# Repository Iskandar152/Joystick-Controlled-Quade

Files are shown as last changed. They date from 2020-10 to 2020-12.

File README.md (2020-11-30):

# Joystick-Controlled-Quade

## Project Goal

Creating a quadraped robot that uses an ultra sonic sensor and joystick to allow wireless control. The information from the ultra sonic sensor will allow the controller to guide the robot even if the controller cannot see where it is.

## MSP432 UART Connection

Based off [TI UART example code](http://dev.ti.com/tirex/explore/node?node=AHgBmlbzFK.HTw3HuKF7Cw__z-lQYNj__LATEST)
This example was chosen as the base because the baud rate was already set at 9600 which is necessary for communication with the Arduino Uno.

Altered to allow communication over the 3.2 and 3.3 pins on the MSP432 so that it can be connected to and Arduino Uno. It works with a receive interrupt that will then transmit the information from the ultra sonic sensor. 

## Arduino Blynk Code

Based off examples from the Blynk library, [Joystick Example](https://examples.blynk.cc/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) and [Virtual Display](https://examples.blynk.cc/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).
Our code combines these examples and alters the display so that it is comstantly updating whenever new data is available.

This was an easy way to have a wireless connection with the MSP432 that just needed the addition of the UART communication to work with the TX and RX pins. The code creates an array for the joystick inputs and writes the sensor values to a digital display.

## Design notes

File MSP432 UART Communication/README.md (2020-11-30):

# MSP432 UART Communication

## Preface
This code is based off the [TI UART example code](http://dev.ti.com/tirex/explore/node?node=AHgBmlbzFK.HTw3HuKF7Cw__z-lQYNj__LATEST)

## Information
This code is the base for the UART communication through the 3.2 and 3.3 pins that works with a reciving interrupt.
This is used so that we can transmit the ultra sonic sensor values through the UART to the Arduino.

This allows us to utialize that Blynk libraries that work with Arduinos to transmit the information wirelessly using the ESP8266 esp-01 module.

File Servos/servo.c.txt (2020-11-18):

//SMCLK = 48MHZ/4 = 12 MHZ, 83.33 ns
//Counter counts up to TA0CCR0 and backs down
//Let Timerclock period T = 8/12MHZ = 666.7ns
//Period of P2.4 is period * 1.333 us, duty cycle is duty / period
//Period of P2.5 is period * 1.333 us, duty cycle is duty2/period
Referenced from the Texas Instruments training videos, will be changing it up a little to be more specific to our project 
//https://training.ti.com/ti-rslk-module-13-lab-video-13-2-interrupt-latency?context=1135347-1139304-1134881
#include<msp.h> //Include the library files for the board. This includes the msp432p401r

void PWM_Init12(uint16_t period, uint16_t duty1, uint16_t duty2){
    P2 -> DIR |= 0x30;     //P2.4, P2.5 output
    P2 -> SEL0 |= 0x30;    //P2.4, P2.5 Timer 0A functions
    P2 -> SEL1 &= -0x30;   //P2.4, P2.5 Timer0A functions
    TIMER_A0 -> CCTL[0] = 0x0080;    //CCIO toggle
    TIMER_A0 -> CCR[0] = period;     //Period is 2*period*8*83.33ns is 1.333*period
    TIMER_A0 -> EX0 = 0x0000;        //divide by 1
    TIMER_A0 -> CCTL[1] = 0x0040;    //CCR1 toggle/reset
    TIMER_A0 -> CCR[1] = duty1;      //CCR1 duty cycle is duty1/period
    TIMER_A0 -> CTL = 0x02F0;         //SMCLK = 12MHZ, divide by 8, up-down mode

}

//change duty cycle of PWM output on P2.4
//Inputs: duty1
//Outputs: None
//Period of P2.4 is 2*period*666.7ns, duty cycle is duty1/period
void PWM_Duty1(uint16_t duty1){
    TIMER_A0 -> CCR[1] = duty1;
}

void PWM_Duty2(uint16_t duty2){
    TIMER_A0 -> CCR[2] = duty2;
}

int main(void){
    WDT_A->CTL= WDT_A_CTL_PW | WDT_A_CTL_HOLD; //Stop watchdog timer
    PWM_Init12(1.5,1,1);
    PWM_Duty1(2);
    /*
    while(1){
        PWM_Init12(1.5,1,1);
        //P2 -> OUT |= 0x01;
        //for(int i = 0; i < 50000; i++);
        //P2 -> OUT ^= 0x01;
    }
    */
}

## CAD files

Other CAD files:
MSP432 UART Communication/Debug/ccs/startup_msp432p401r_ccs.obj

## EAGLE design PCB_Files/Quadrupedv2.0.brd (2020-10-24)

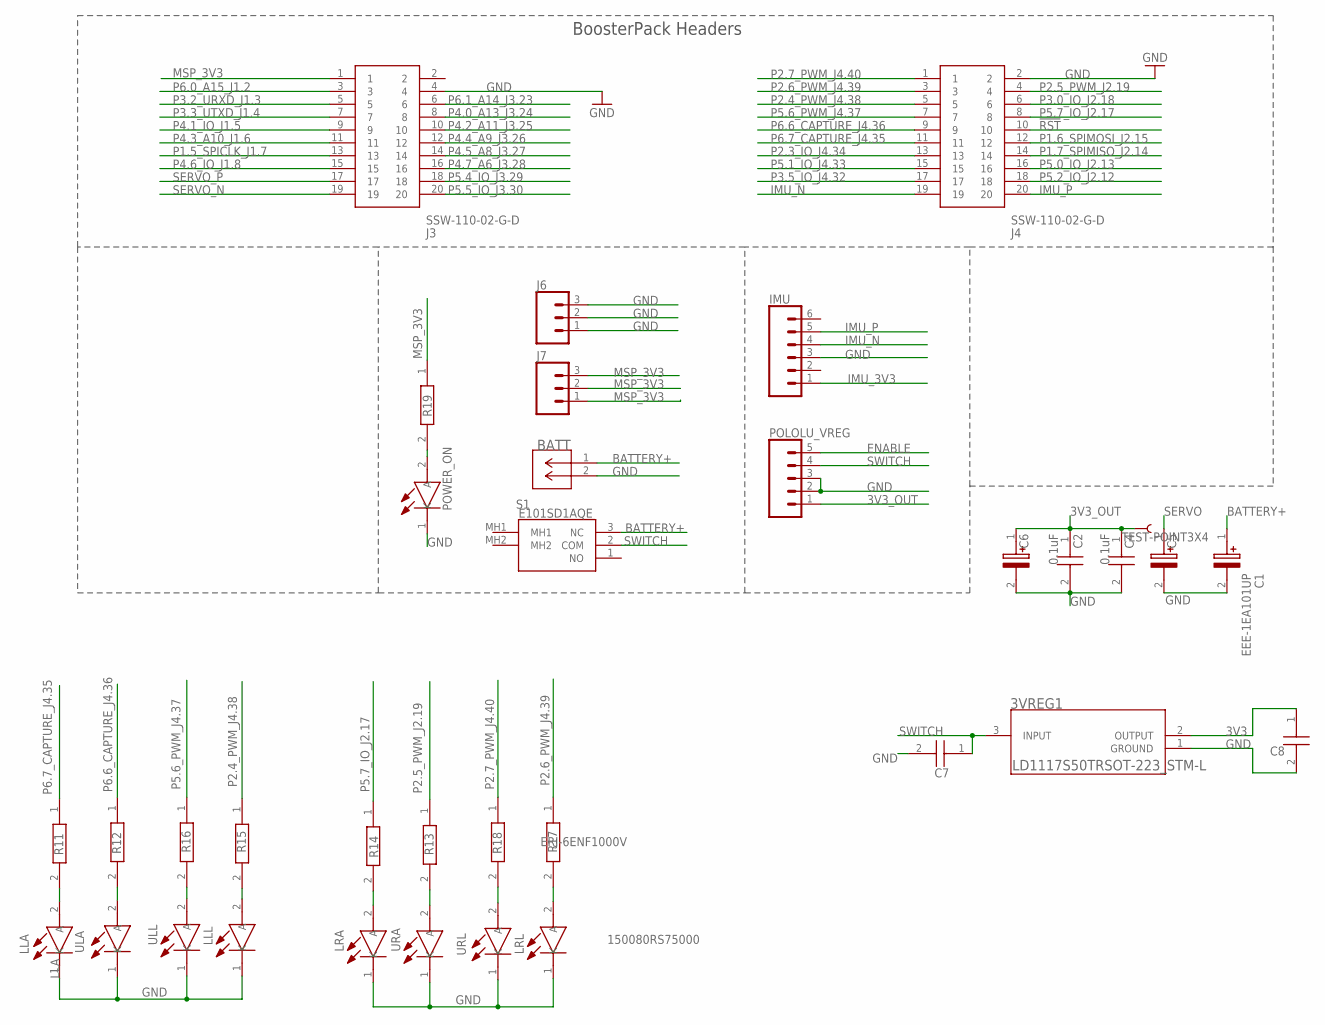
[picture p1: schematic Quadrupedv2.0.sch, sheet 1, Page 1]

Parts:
3VREG1: LD1117S50TRSOT-223_STM-L; SOT-223_STM-L
BATT: 640456-2; CONN2_640456-2_TEC
C1, C5, C6: EEE-1EA101UP; CAPAE830X650N
C2, C4: 0.1uF; CAPC2012X88N
C7, C8: C0805C104K5RAC7411; CAPC2012X88N
IMU: CONN_06SILK_FEMALE_PTH; 1X06
J3, J4: SSW-110-02-G-D; SAMTEC_SSW-110-02-G
J6, J7: CONN_03CONN_3F; 1X03_FEMALE
LLA: 150080RS75000; LEDC2012X80N
LLL: 150080RS75000; LEDC2012X80N
LRA: 150080RS75000; LEDC2012X80N
LRL: 150080RS75000; LEDC2012X80N
POLOLU_VREG: CONN_05; 1X05
POWER_ON: 150080RS75000; LEDC2012X80N
R11, R12, R13, R14, R15, R16, R17, R18, R19: ERJ-6ENF1000V; RESC2012X70N
S1: E101SD1AQE
TP22: TEST-POINT3X4; PAD.03X.04
ULA: 150080RS75000; LEDC2012X80N
ULL: 150080RS75000; LEDC2012X80N
URA: 150080RS75000; LEDC2012X80N
URL: 150080RS75000; LEDC2012X80N

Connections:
3V3: 3VREG1.2 (OUTPUT), C8.1; also elsewhere on the board
3V3_OUT: C2.1, C4.1, C6.1 (+), POLOLU_VREG.1, TP22.P$1; also elsewhere on the board
!RST: J4.10
BATTERY+: BATT.1, C1.1 (+), S1.3 (NC)
ENABLE: POLOLU_VREG.5
GND: 3VREG1.1 (GROUND), BATT.2, C1.2 (-), C2.2, C4.2, C5.2 (-), C6.2 (-), C7.2, C8.2, IMU.3, J3.4, J4.2, J6.1, J6.2, J6.3, LLA.1 (K), LLL.1 (K), LRA.1 (K), LRL.1 (K), POLOLU_VREG.2, POLOLU_VREG.3, POWER_ON.1 (K), ULA.1 (K), ULL.1 (K), URA.1 (K), URL.1 (K); also elsewhere on the board
IMU_3V3: IMU.1; also elsewhere on the board
IMU_N: IMU.4, J4.19
IMU_P: IMU.5, J4.20
MSP_3V3: J3.1, J7.1, J7.2, J7.3, R19.1; also elsewhere on the board
unnamed: R12.2, ULA.2 (A)
unnamed: LLA.2 (A), R11.2
unnamed: R16.2, ULL.2 (A)
unnamed: LLL.2 (A), R15.2
unnamed: R13.2, URA.2 (A)
unnamed: LRA.2 (A), R14.2
unnamed: R18.2, URL.2 (A)
unnamed: LRL.2 (A), R17.2
unnamed: POWER_ON.2 (A), R19.2
P1.5_SPICLK_J1.7: J3.13
P1.6_SPIMOSI_J2.15: J4.12
P1.7_SPIMISO_J2.14: J4.14
P2.3_IO_J4.34: J4.13
P2.4_PWM_J4.38: J4.5, R15.1
P2.5_PWM_J2.19: J4.4, R13.1
P2.6_PWM_J4.39: J4.3, R17.1
P2.7_PWM_J4.40: J4.1, R18.1
P3.0_IO_J2.18: J4.6
P3.2_URXD_J1.3: J3.5
P3.3_UTXD_J1.4: J3.7
P3.5_IO_J4.32: J4.17
P4.0_A13_J3.24: J3.8
P4.1_IO_J1.5: J3.9
P4.2_A11_J3.25: J3.10
P4.3_A10_J1.6: J3.11
P4.4_A9_J3.26: J3.12
P4.5_A8_J3.27: J3.14
P4.6_IO_J1.8: J3.15
P4.7_A6_J3.28: J3.16
P5.0_IO_J2.13: J4.16
P5.1_IO_J4.33: J4.15
P5.2_IO_J2.12: J4.18
P5.4_IO_J3.29: J3.18
P5.5_IO_J3.30: J3.20
P5.6_PWM_J4.37: J4.7, R16.1
P5.7_IO_J2.17: J4.8, R14.1
P6.0_A15_J1.2: J3.3
P6.1_A14_J3.23: J3.6
P6.6_CAPTURE_J4.36: J4.9, R12.1
P6.7_CAPTURE_J4.35: J4.11, R11.1
SERVO: C5.1 (+); also elsewhere on the board
SERVO_N: J3.19; also elsewhere on the board
SERVO_P: J3.17; also elsewhere on the board
SWITCH: 3VREG1.3 (INPUT), C7.1, POLOLU_VREG.4, S1.2 (COM)

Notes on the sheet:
BoosterPack Headers

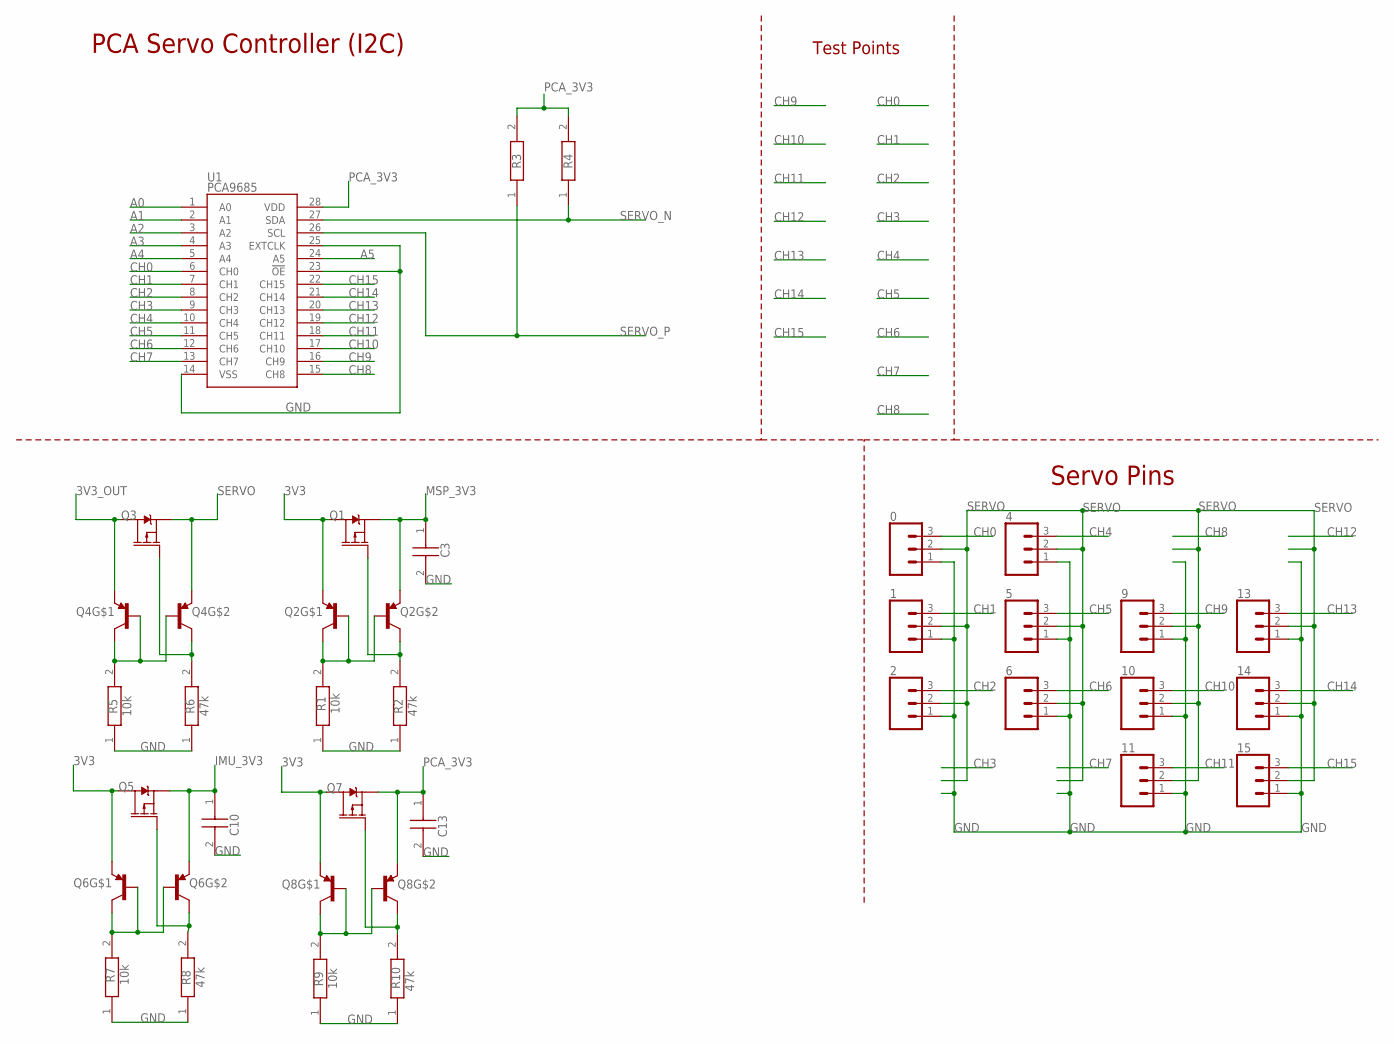
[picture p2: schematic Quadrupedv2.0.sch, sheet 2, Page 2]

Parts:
0, 1, 2, 4, 5, 6, 9, 10, 11, 13, 14, 15: CONN_03; 1X03MALE
C3, C10, C13: C0805C104K5RAC7411; CAPC2012X88N
Q1, Q3, Q5, Q7: 2.5A/30V/105mΩ; SOT23-3
Q2, Q4, Q6, Q8: TRANS_PNP_DUALSOT-363; SOT363_PHILIPS
R1, R5, R7, R9: 10k; RESC2012X70N
R2, R6, R8, R10: 47k; RESC2012X70N
R3, R4: ERJ-6ENF1000V; RESC2012X70N
U1: PCA9685; TSSOP-28_4MM

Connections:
3V3: Q1.3 (D), Q2.1 (E), Q5.3 (D), Q6.1 (E), Q7.3 (D), Q8.1 (E); also elsewhere on the board
3V3_OUT: Q3.3 (D), Q4.1 (E); also elsewhere on the board
A0: U1.1 (A0)
A1: U1.2 (A1)
A2: U1.3 (A2)
A3: U1.4 (A3)
A4: U1.5 (A4)
A5: U1.24 (A5)
CH0: 0.3, U1.6 (CH0)
CH1: 1.3, U1.7 (CH1)
CH2: 2.3, U1.8 (CH2)
CH3: U1.9 (CH3)
CH4: 4.3, U1.10 (CH4)
CH5: 5.3, U1.11 (CH5)
CH6: 6.3, U1.12 (CH6)
CH7: U1.13 (CH7)
CH8: U1.15 (CH8)
CH9: 9.3, U1.16 (CH9)
CH10: 10.3, U1.17 (CH10)
CH11: 11.3, U1.18 (CH11)
CH12: U1.19 (CH12)
CH13: 13.3, U1.20 (CH13)
CH14: 14.3, U1.21 (CH14)
CH15: 15.3, U1.22 (CH15)
GND: 0.1, 1.1, 2.1, 4.1, 5.1, 6.1, 9.1, 10.1, 11.1, 13.1, 14.1, 15.1, C3.2, C10.2, C13.2, R1.1, R2.1, R5.1, R6.1, R7.1, R8.1, R9.1, R10.1, U1.14 (VSS), U1.23 (!OE), U1.25 (EXTCLK); also elsewhere on the board
IMU_3V3: C10.1, Q5.2 (S), Q6.4 (E); also elsewhere on the board
MSP_3V3: C3.1, Q1.2 (S), Q2.4 (E); also elsewhere on the board
unnamed: Q7.1 (G), Q8.3 (C), R10.2
unnamed: Q8.2 (B), Q8.5 (B), Q8.6 (C), R9.2
unnamed: Q1.1 (G), Q2.3 (C), R2.2
unnamed: Q2.2 (B), Q2.5 (B), Q2.6 (C), R1.2
unnamed: Q5.1 (G), Q6.3 (C), R8.2
unnamed: Q6.2 (B), Q6.5 (B), Q6.6 (C), R7.2
unnamed: Q4.2 (B), Q4.5 (B), Q4.6 (C), R5.2
unnamed: Q3.1 (G), Q4.3 (C), R6.2
PCA_3V3: C13.1, Q7.2 (S), Q8.4 (E), R3.2, R4.2, U1.28 (VDD)
SERVO: 0.2, 1.2, 2.2, 4.2, 5.2, 6.2, 9.2, 10.2, 11.2, 13.2, 14.2, 15.2, Q3.2 (S), Q4.4 (E); also elsewhere on the board
SERVO_N: R4.1, U1.27 (SDA); also elsewhere on the board
SERVO_P: R3.1, U1.26 (SCL); also elsewhere on the board

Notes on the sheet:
PCA Servo Controller (I2C)
Test Points
Servo Pins

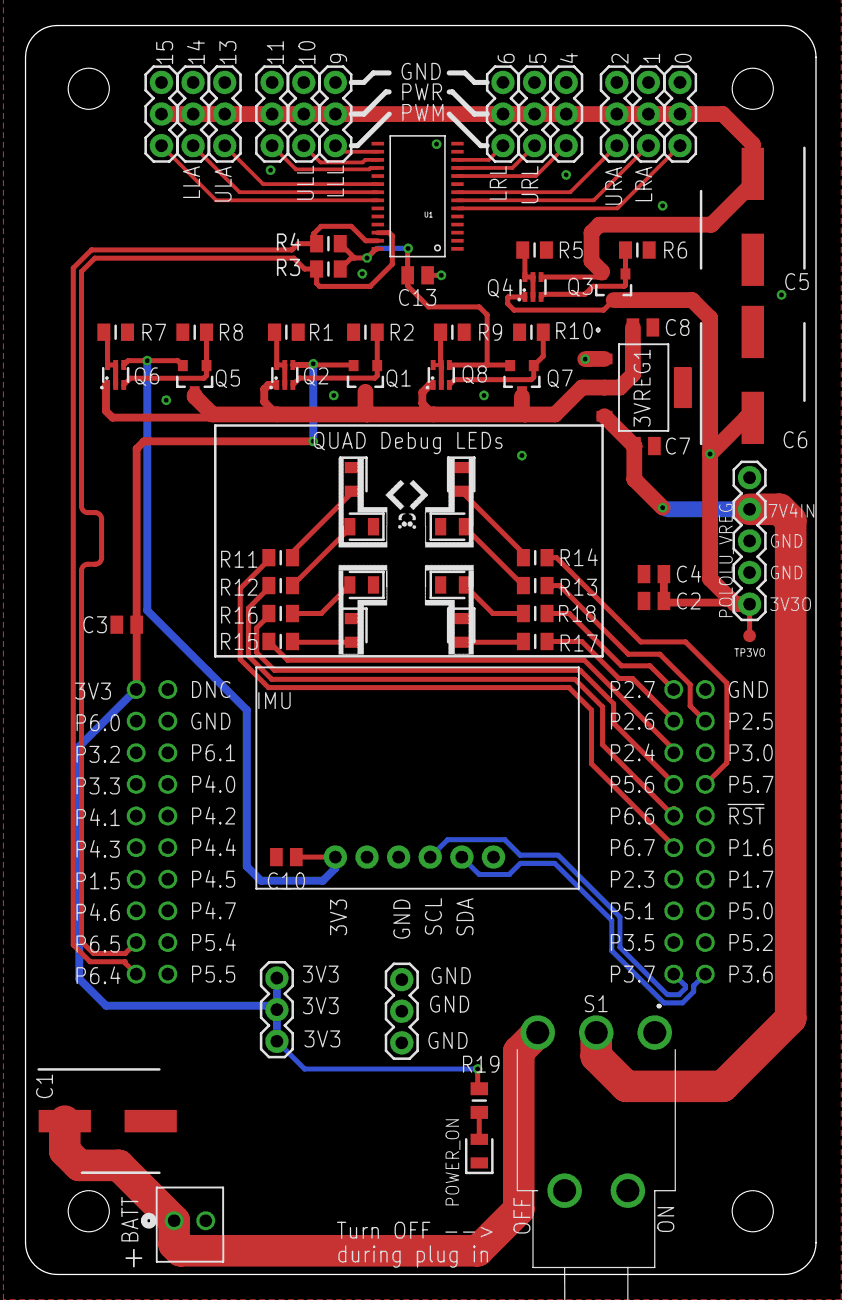
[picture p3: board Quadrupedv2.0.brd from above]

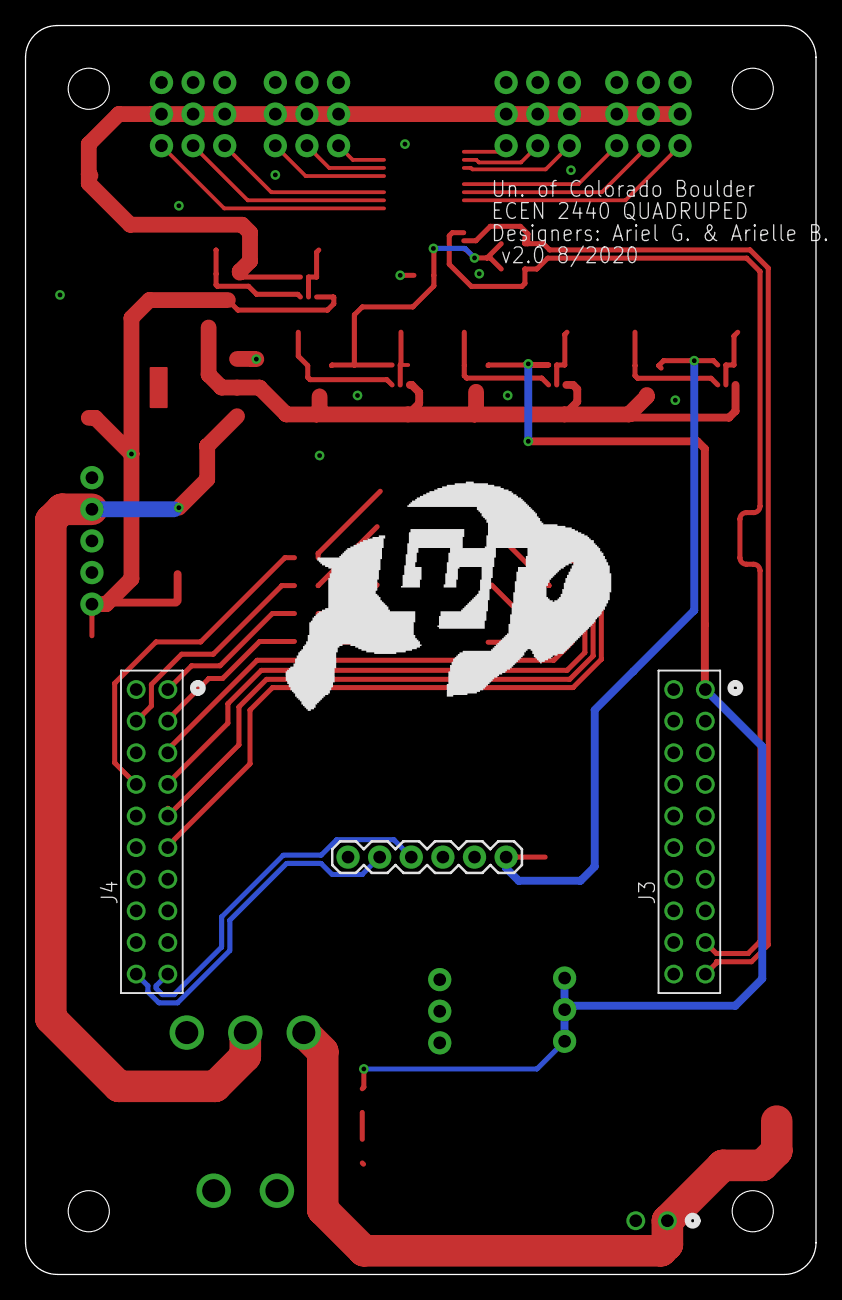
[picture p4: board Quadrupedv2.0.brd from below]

Board: 2 copper layers, 63.5 x 100.3 mm, 71 parts (4 on the bottom side), 50 nets.

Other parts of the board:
U$1: DEBUGLEDS
U$2: SKUBUFFS

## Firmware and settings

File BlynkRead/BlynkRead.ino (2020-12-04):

/*************************************************************
  Download latest Blynk library here:
    https://github.com/blynkkk/blynk-library/releases/latest

  Blynk is a platform with iOS and Android apps to control
  Arduino, Raspberry Pi and the likes over the Internet.
  You can easily build graphic interfaces for all your
  projects by simply dragging and dropping widgets.

    Downloads, docs, tutorials: http://www.blynk.cc
    Sketch generator:           http://examples.blynk.cc
    Blynk community:            http://community.blynk.cc
    Follow us:                  http://www.fb.com/blynkapp
                                http://twitter.com/blynk_app

  Blynk library is licensed under MIT license
  This example code is in public domain.

 *************************************************************
  WARNING!
    It's very tricky to get it working. Please read this article:
    http://help.blynk.cc/hardware-and-libraries/arduino/esp8266-with-at-firmware

  This example shows how to send values to the Blynk App,
  when there is a widget, attached to the Virtual Pin and it
  is set to some frequency

  Project setup in the app:
    Value Display widget attached to V5. Set any reading
    frequency (i.e. 1 second)
 *************************************************************/

/* Comment this out to disable prints and save space */
#define BLYNK_PRINT Serial


#include <ESP8266_Lib.h>
#include <BlynkSimpleShieldEsp8266.h>

int datain;

// You should get Auth Token in the Blynk App.
// Go to the Project Settings (nut icon).
char auth[] = "YourAuthToken";

// Your WiFi credentials.
// Set password to "" for open networks.
char ssid[] = "YourNetworkName";
char pass[] = "YourPassword";

// or Software Serial on Uno, Nano...
#include <SoftwareSerial.h>
SoftwareSerial EspSerial(2, 3); // RX, TX

// Your ESP8266 baud rate:
#define ESP8266_BAUD 9600

ESP8266 wifi(&EspSerial);

// Use Virtual pin 5 for uptime display
#define SENSOR V5


// This function tells Arduino what to do if there is a Widget
// which is requesting data for Virtual Pin (5)
BLYNK_READ(SENSOR)
{
  // This command writes Arduino's uptime in seconds to Virtual Pin (5)
  Blynk.virtualWrite(SENSOR, datain);
}

BLYNK_WRITE(V1) {
  int x = param[0].asInt();
  int y = param[1].asInt();

  // Do something with x and y
  Serial.print("X = ");
  Serial.print(x);
  Serial.print("; Y = ");
  Serial.println(y);
}

void setup()
{
  // Debug console
  Serial.begin(9600);

  // Set ESP8266 baud rate
  EspSerial.begin(ESP8266_BAUD);
  delay(10);

  Blynk.begin(auth, wifi, ssid, pass);
}

void loop()
{
  Blynk.run();

  if (Serial.available())
  {
    int datain = Serial.read();
    Serial.print(" Sensor = ");
    Serial.print(datain);
  }
  /* Joystick values are from 0 to 255
   *  Stationary Position 127 127
   *  x goes to zero on the left side y zero on buttom
   *  Forward and right means largest number and smallest values are backwars and left
   *  Without knowing the full capabilities of the servos and driver I dont know how to limit their movements
   */
}

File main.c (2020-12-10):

// Joe Gamel, James Brennan
// ECEN2440 Final Project
// joystick, HC-SR04 (US sensor) peripheral
// main.c
// Version 1.7 - Last update: 12/9/20

#include "msp.h"
#include "js.h"
#include "HC-SR04.h"
#include <stdio.h>

#define   Num_of_Results   8
int xin[Num_of_Results];
int yin[Num_of_Results];
int index;

void main(void) {
	WDT_A->CTL = WDT_A_CTL_PW | WDT_A_CTL_HOLD;		// stop watchdog timer

	__disable_irq();            //disable interrupts

	stop_pulse();
	stop_capture();
	config_TimerA0_nvic();
	config_ADC_NVIC();
	config_pulse_timer();
	config_pulse_gpio();
	config_capture_timer();
	config_US_gpio();
	config_js_gpio();
    config_adc();

    __enable_irq();             //enable interrupts

    start_pulse();
    start_capture();
    adc_convert();

    while(1) {

    }
}

void ADC14_IRQHandler(void) {

        yin[index] = ADC14->MEM[0];
        xin[index] = ADC14->MEM[1];
        index = (index + 1) & 0x7;          // Increment results index, modulo

        printf("x-axis: %d\n", xin[index]);
        printf("y-axis: %d\n", yin[index]);
        printf("index: %d\n", index);

    ADC14->CLRIFGR0 |= ADC14_CLRIFGR0_CLRIFG0; // clr flg
    ADC14->CLRIFGR0 |= ADC14_CLRIFGR0_CLRIFG1; // clr flg
}

void TA0_N_IRQHandler(void){
    double a = 0;
    //printf("%.5lf", a);
    TIMER_A0->CCTL[1] &= ~TIMER_A_CCTLN_CCIFG; //clear flag
    //TIMER_A1->CCTL[1] &= ~TIMER_A_CCTLN_CCIFG; //clear flag
    P1->OUT ^= BIT0;                            //toggle LED
    P2->OUT ^= BIT0;

    //the following code would preferably be moved to main and done on the processor

    a = TIMER_A1->CCR[2] - TIMER_A1->CCR[1];    //substracting positive edge count from negative edge
    a=(a/(187500));   //converts count to time based on input clock frequency
    a=a*(170);   //converts time to distance
    a=(.2422)*a-.0037;    //error correction function, experimentally determined, may need to be adjusted for individual sensors
    printf("%.5lf \n", a);  //prints distance to the console, useful for debugging
}

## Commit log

2020-11-30 Create Wifi Arduino UART Communication
2020-11-30 Basic MSP432 UART communication
    Altered [TI UART example code](http://dev.ti.com/tirex/explore/node?node=AHgBmlbzFK.HTw3HuKF7Cw__z-lQYNj__LATEST)
    [startup_msp432p401r_ccs.obj]

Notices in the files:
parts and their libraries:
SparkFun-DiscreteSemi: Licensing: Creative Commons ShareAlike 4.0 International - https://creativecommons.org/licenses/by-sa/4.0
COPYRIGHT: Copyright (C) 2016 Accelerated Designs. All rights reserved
